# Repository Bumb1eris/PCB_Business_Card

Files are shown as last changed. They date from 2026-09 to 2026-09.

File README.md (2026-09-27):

# Snake PCB Business Card

A business card you can play: a tilt-controlled Snake game on a 7×5 LED matrix, powered by a coin cell.

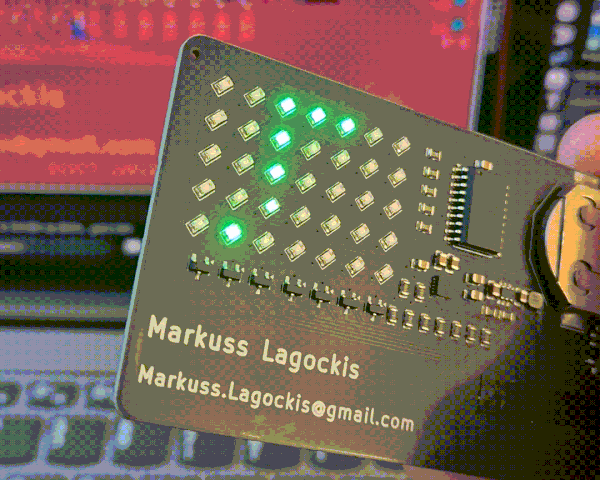
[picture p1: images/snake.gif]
Snake game running on the card


## Why I built it

I designed this card to hand out at TechIndustry, the largest tech expo in the Baltics. A paper card gets thrown away. A card that plays Snake gets passed around.

The original idea was a fluid simulation, but on a 7×5 matrix it just looked like random blinking, so it became Snake instead.

## How to play

- **Flip the switch.** The snake starts moving.
- **Tilt the card** to steer.
- **Crash, and your score appears.** The matrix fills one LED per point. If you fill the whole screen, it rolls over to a second score screen.
- **Shake the card** to start a new game.

## Hardware

| | |
|---|---|
| **MCU** | ATtiny1616 |
| **Accelerometer** | MMA8451 |
| **Power** | CR2032 coin cell → MCP1640 boost converter → stable 3.3 V |
| **Display** | 35 LEDs in a 7×5 multiplexed matrix |
| **PCB** | 2-layer, credit card size, fabricated and assembled by JLCPCB |
| **Cost** | ~€6 per card, assembled |

### How the matrix works

The rows are driven directly from the MCU pins through 22 Ω resistors. The columns are switched by a row of SOT-23 transistors along the bottom of the board. The firmware scans through the columns fast enough that the whole matrix looks lit at once.

The LEDs are rotated 45°. Together with the transistor array underneath, the matrix wiring is some of my cleanest routing work, and it worked on the first try.

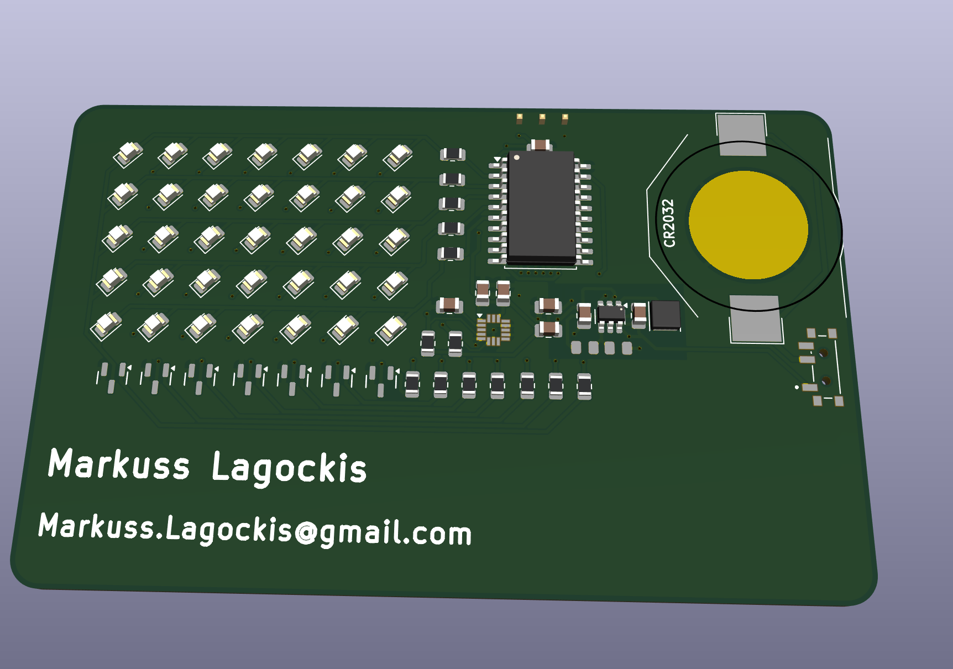
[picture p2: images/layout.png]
PCB layout

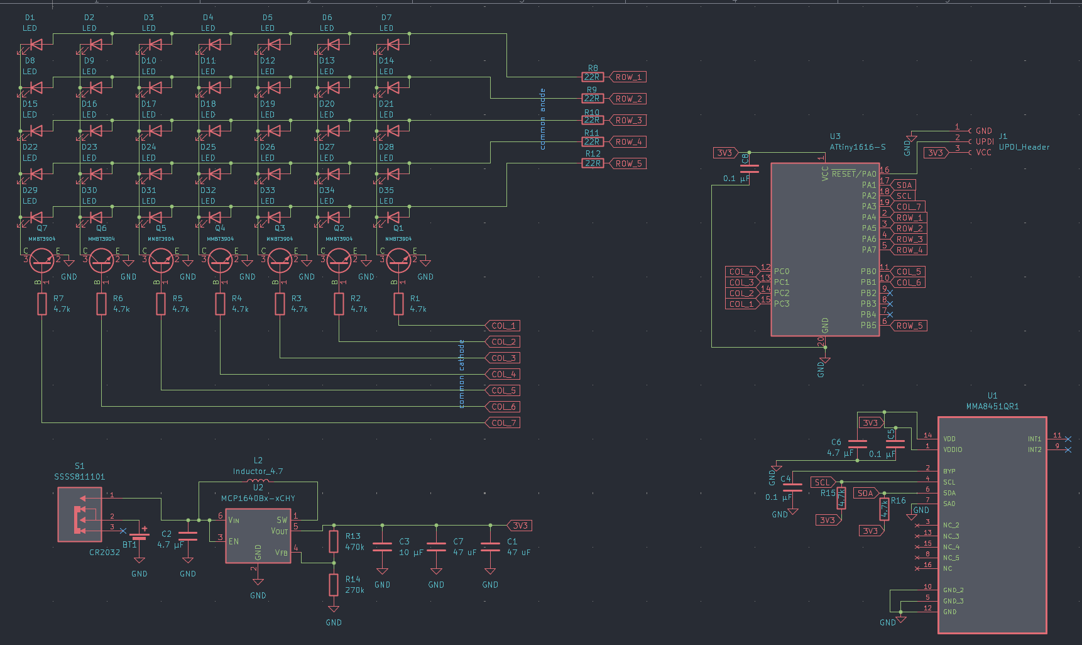
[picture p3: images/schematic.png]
Schematic


## Battery life

- **Switched on:** about 3 days of continuous use
- **Switched off:** about a year or two in storage

## Firmware

Written in the Arduino IDE. The ATtiny1616 is programmed over UPDI, using an Arduino Nano as a makeshift UPDI programmer.

### Flashing

1. Install the [megaTinyCore](https://github.com/SpenceKonde/megaTinyCore) board package in the Arduino IDE.
2. Flash an Arduino Nano with the UPDI programmer sketch (jtag2updi) and wire it to the card's UPDI pin.
3. Select **ATtiny1616** as the board and the Nano as the programmer.
4. Open `firmware/snake/snake.ino` and upload.

## Repository structure

```
firmware/
  snake/          Arduino sketch
hardware/
  kicad/          KiCad project files
  schematic.pdf
  gerbers/        ready to send to a fab
  bom.csv
images/
```

## Status

✅ **v1 finished.** Cards were built, handed out, and work as designed.

🚧 **v2 planned.** The main change: swap the MMA8451 for a proper IMU. The accelerometer isn't responsive enough, so steering can feel sluggish.

## License

Hardware/Firmware: MIT

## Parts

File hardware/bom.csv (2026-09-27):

Designator | Footprint | Quantity | Value | LCSC Part #
BT1 | CR2032 | 1 | CR2032
C1, C7 | 0805 | 2 | 47 uF
C2, C6 | 0805 | 2 | 4.7 µF
C3 | 0805 | 1 | 10 µF
C4, C5, C8 | 0805 | 3 | 0.1 µF
D1, D10, D11, D12, D13, D14, D15, D16, D17, D18, D19, D2, D20, D21, D22, D23, D24, D25, D26, D27, D28, D29, D3, D30, D31, D32, D33, D34, D35, D4, D5, D6, D7, D8, D9 | 0805 | 35 | LED | C2297
J1 | UPDI_P=2.54mm | 1 | UPDI_Header
L2 | L_APV_ANR3010 | 1 | Inductor_4.7 | C135233
Q1, Q2, Q3, Q4, Q5, Q6, Q7 | Q_SOT-23 | 7 | MMBT3904 | C7420353
R1, R15, R16, R2, R3, R4, R5, R6, R7 | 0805 | 9 | 4.7k
R10, R11, R12, R8, R9 | 0805 | 5 | 22R
R13 | R_0805 | 1 | 470k
R14 | R_0805 | 1 | 270k
S1 | SW_SSSS811101Real | 1 | SSSS811101
U1 | QFN50P300X300X100-16N | 1 | MMA8451QR1 | C118083
U2 | SOT-23-6 | 1 | MCP1640Bx-xCHY
U3 | SOIC-20W_7.5x12.8mm_P1.27mm | 1 | ATtiny1616-S

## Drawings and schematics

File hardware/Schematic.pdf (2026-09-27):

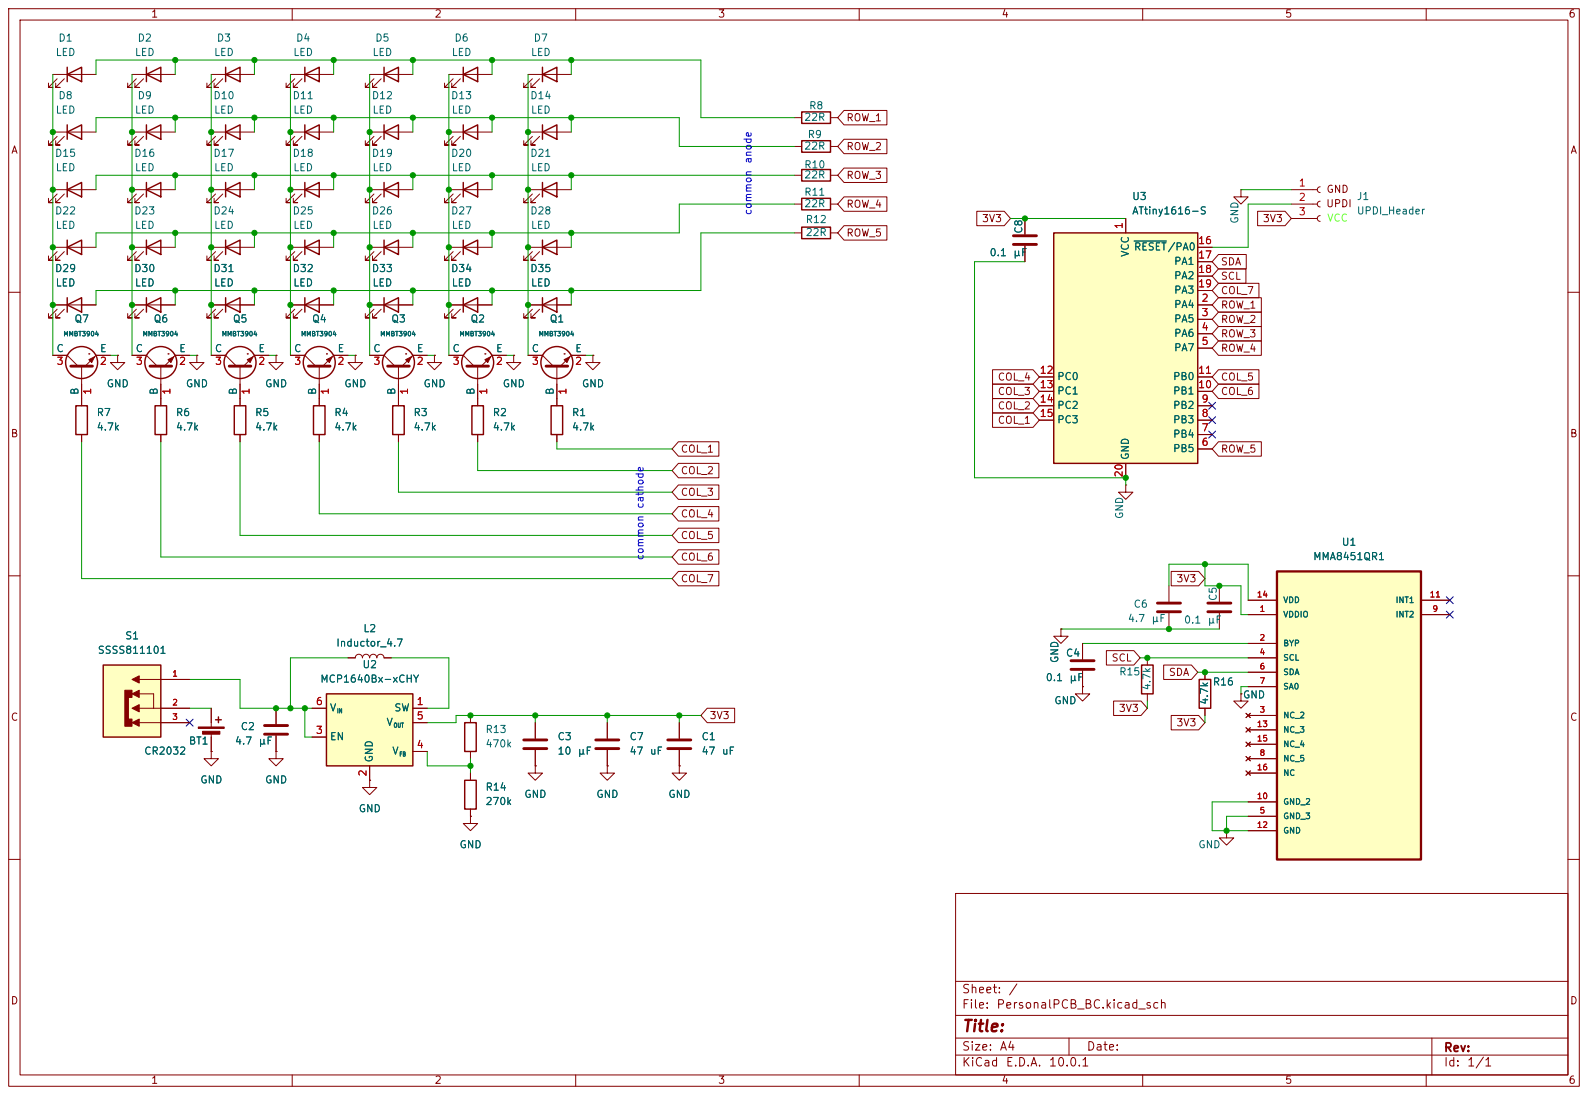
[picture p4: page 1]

D15 LED | D16 LED | LED | D18 LED | MMBT3904 D12 D19 LED | D20 LED

D22 LED | D23 LED | D24 LED | LED | LED | D27 LED

D29 D29 LED LED | D30 LED | D31 LED LED | D32 D32 LED | D33 D33 LED LED | D34 LED LED | D35 D35 LED

Size: A4 | Rev:
KiCad E.D.A. 10.0.1 | Id: 1/1

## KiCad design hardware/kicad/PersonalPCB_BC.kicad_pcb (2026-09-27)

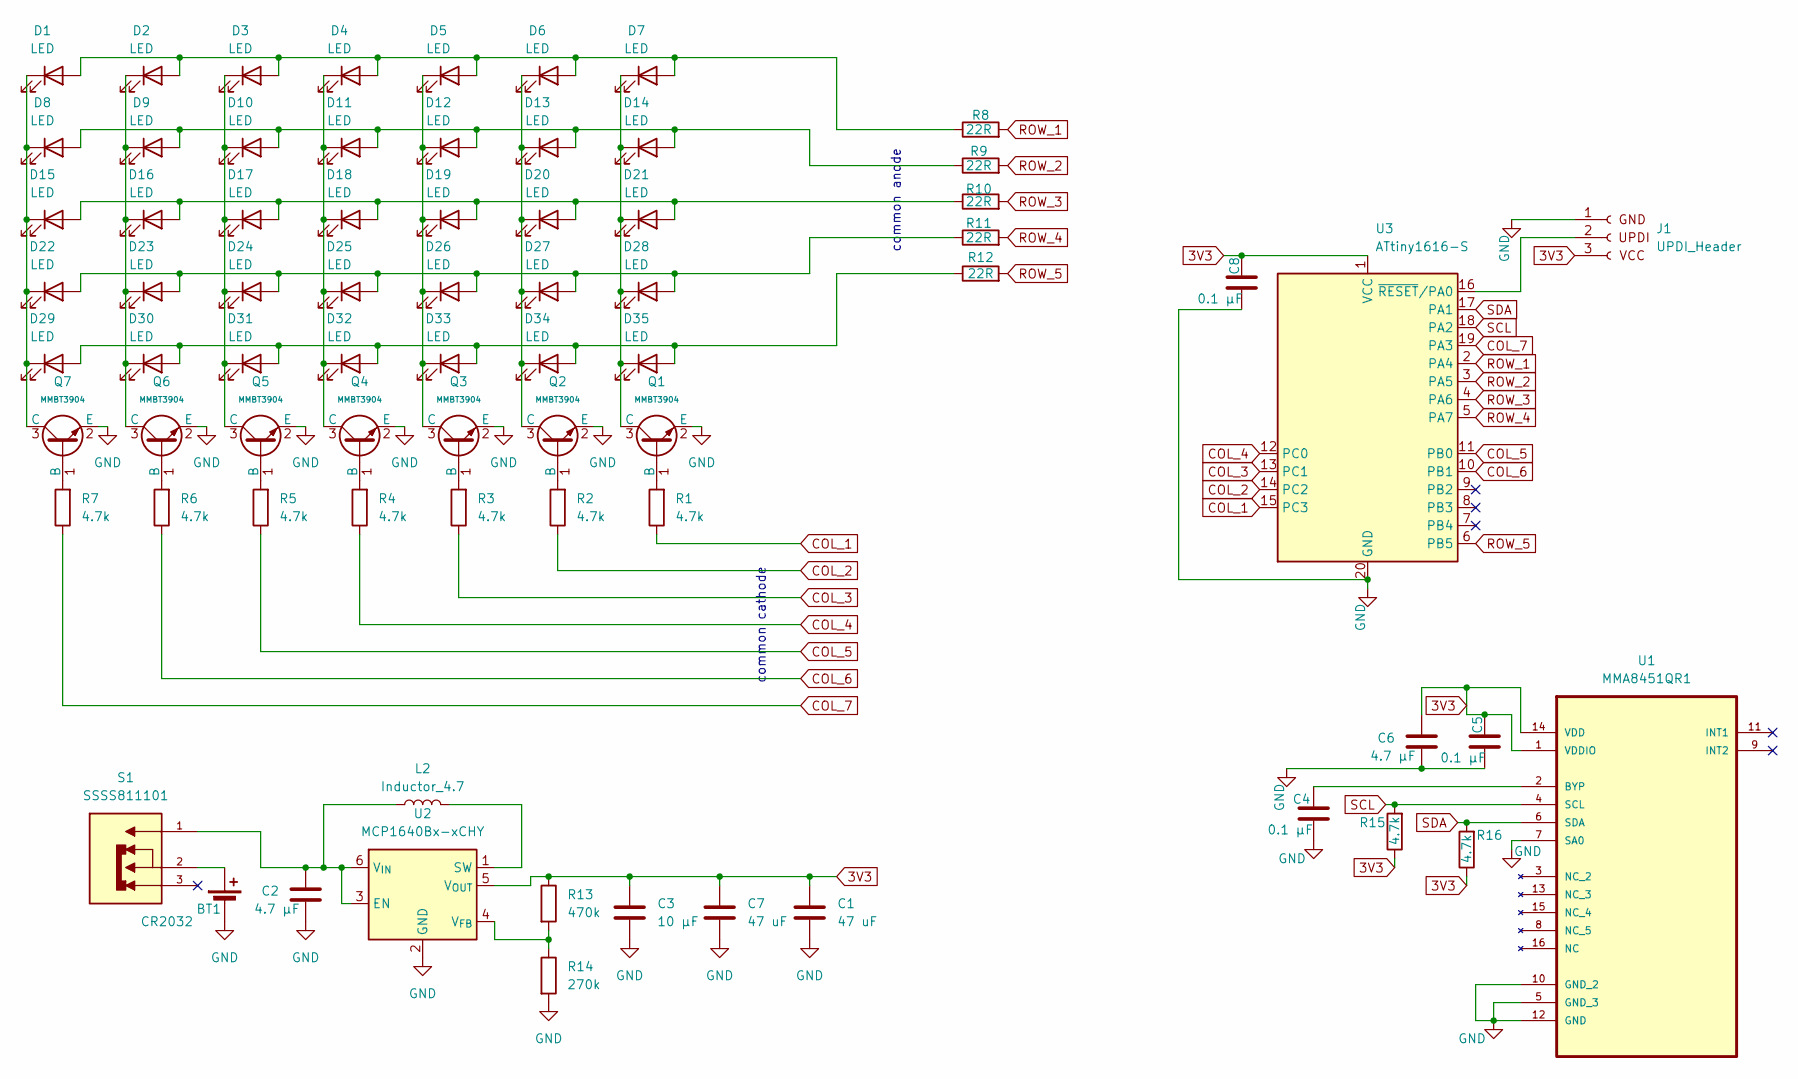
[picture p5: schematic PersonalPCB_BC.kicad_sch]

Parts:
BT1: CR2032
C1, C7: 47 uF; C_0805_2012Metric; JLCPCB Part # C16780
C2, C6: 4.7 µF; C_0805_2012Metric
C3: 10 µF; C_0805_2012Metric
C4, C5, C8: 0.1 µF; C_0805_2012Metric
D1, D2, D3, D4, D5, D6, D7, D8, D9, D10, D11, D12, D13, D14, D15, D16, D17, D18, D19, D20, D21, D22, D23, D24, D25, D26, D27, D28, D29, D30, D31, D32, D33, D34, D35: LED; LED_0805_2012Metric; JLCPCB Part # C2297
J1: UPDI_Header; UPDI_P=2.54mm
L2: Inductor_4.7; L_APV_ANR3010; JLCPCB Part # C135233
Q1, Q2, Q3, Q4, Q5, Q6, Q7: MMBT3904; Q_SOT-23; Part MMBT3904; LCSC C7420353
R1, R2, R3, R4, R5, R6, R7, R15, R16: 4.7k; R_0805_2012Metric
R8, R9, R10, R11, R12: 22R; R_0805_2012Metric
R13: 470k; R_0805
R14: 270k; R_0805
S1: SSSS811101; SW_SSSS811101Real; PARTREV N/A
U1: MMA8451QR1; QFN50P300X300X100-16N; JLCPCB Part # C118083
U2: MCP1640Bx-xCHY; SOT-23-6
U3: ATtiny1616-S; SOIC-20W_7.5x12.8mm_P1.27mm

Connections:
3V3: C1.1, C3.1, C5.1, C6.1, C7.1, C8.1, J1.3 (VCC), R13.1, R15.1, R16.1, U1.1 (VDDIO), U1.14 (VDD), U2.5 (V_{OUT}), U3.1 (VCC)
COL_1: R1.1, U3.15 (PC3)
COL_2: R2.1, U3.14 (PC2)
COL_3: R3.1, U3.13 (PC1)
COL_4: R4.1, U3.12 (PC0)
COL_5: R5.1, U3.11 (PB0)
COL_6: R6.1, U3.10 (PB1)
COL_7: R7.1, U3.19 (PA3)
GND: BT1.2 (-), C1.2, C2.2, C3.2, C4.2, C5.2, C6.2, C7.2, C8.2, J1.1 (GND), Q1.2 (E), Q2.2 (E), Q3.2 (E), Q4.2 (E), Q5.2 (E), Q6.2 (E), Q7.2 (E), R14.2, U1.5 (GND_3), U1.7 (SA0), U1.10 (GND_2), U1.12 (GND), U2.2 (GND), U3.20 (GND)
unnamed: BT1.1 (+), S1.2
unnamed: D1.2 (A), D2.2 (A), D3.2 (A), D4.2 (A), D5.2 (A), D6.2 (A), D7.2 (A), R8.1
unnamed: D1.1 (K), D8.1 (K), D15.1 (K), D22.1 (K), D29.1 (K), Q7.3 (C)
unnamed: D8.2 (A), D9.2 (A), D10.2 (A), D11.2 (A), D12.2 (A), D13.2 (A), D14.2 (A), R9.1
unnamed: D3.1 (K), D10.1 (K), D17.1 (K), D24.1 (K), D31.1 (K), Q5.3 (C)
unnamed: D4.1 (K), D11.1 (K), D18.1 (K), D25.1 (K), D32.1 (K), Q4.3 (C)
unnamed: D5.1 (K), D12.1 (K), D19.1 (K), D26.1 (K), D33.1 (K), Q3.3 (C)
unnamed: D6.1 (K), D13.1 (K), D20.1 (K), D27.1 (K), D34.1 (K), Q2.3 (C)
unnamed: D7.1 (K), D14.1 (K), D21.1 (K), D28.1 (K), D35.1 (K), Q1.3 (C)
unnamed: D15.2 (A), D16.2 (A), D17.2 (A), D18.2 (A), D19.2 (A), D20.2 (A), D21.2 (A), R10.1
unnamed: D2.1 (K), D9.1 (K), D16.1 (K), D23.1 (K), D30.1 (K), Q6.3 (C)
unnamed: D22.2 (A), D23.2 (A), D24.2 (A), D25.2 (A), D26.2 (A), D27.2 (A), D28.2 (A), R11.1
unnamed: D29.2 (A), D30.2 (A), D31.2 (A), D32.2 (A), D33.2 (A), D34.2 (A), D35.2 (A), R12.1
unnamed: J1.2 (UPDI), U3.16 (~RESET/PA0)
unnamed: Q1.1 (B), R1.2
unnamed: Q2.1 (B), R2.2
unnamed: Q3.1 (B), R3.2
unnamed: Q4.1 (B), R4.2
unnamed: Q5.1 (B), R5.2
unnamed: Q6.1 (B), R6.2
unnamed: Q7.1 (B), R7.2
unnamed: C4.1, U1.2 (BYP)
unnamed: C2.1, L2.1, S1.1, U2.3 (EN), U2.6 (V_{IN})
unnamed: L2.2, U2.1 (SW)
unnamed: R13.2, R14.1, U2.4 (V_{FB})
ROW_1: R8.2, U3.2 (PA4)
ROW_2: R9.2, U3.3 (PA5)
ROW_3: R10.2, U3.4 (PA6)
ROW_4: R11.2, U3.5 (PA7)
ROW_5: R12.2, U3.6 (PB5)
SCL: R15.2, U1.4 (SCL), U3.18 (PA2)
SDA: R16.2, U1.6 (SDA), U3.17 (PA1)

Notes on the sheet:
common cathode
common anode

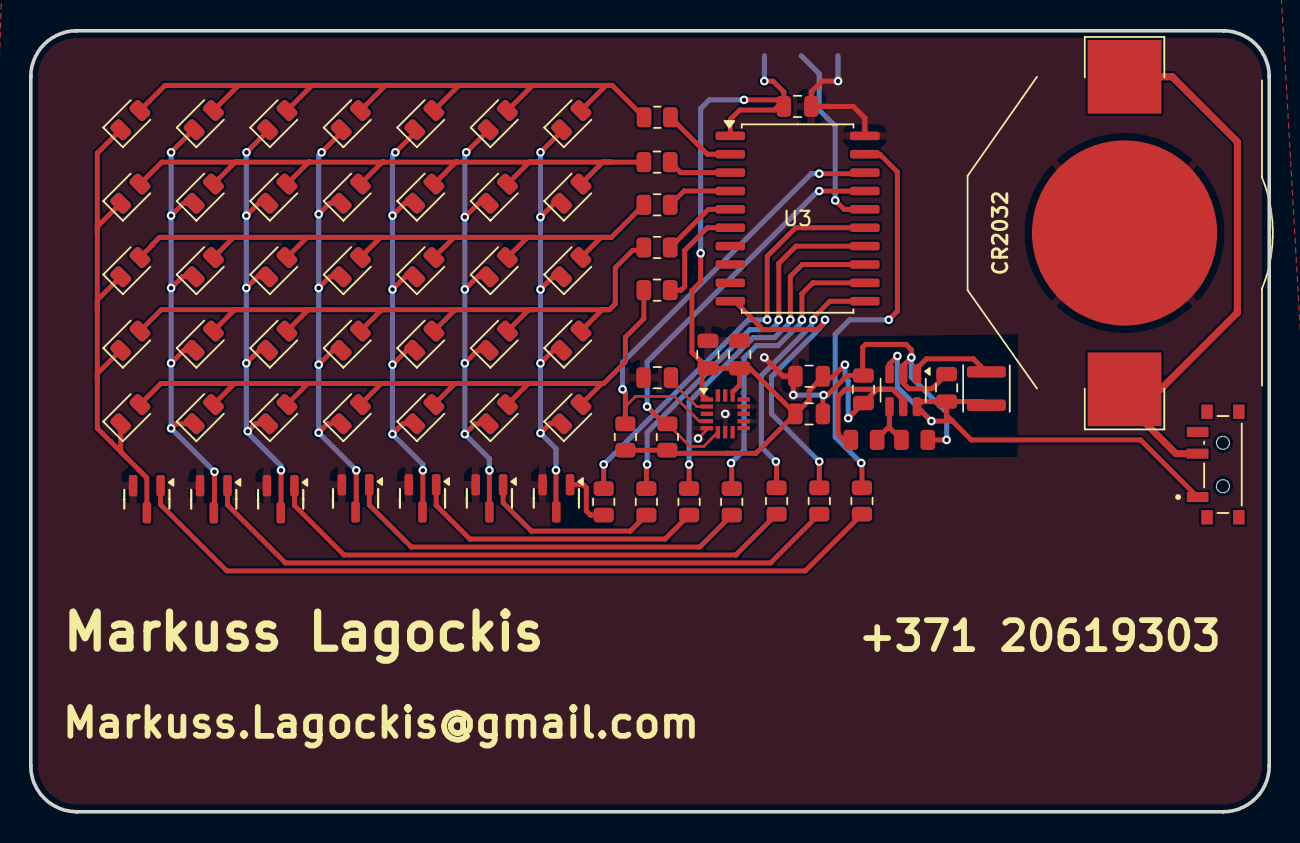
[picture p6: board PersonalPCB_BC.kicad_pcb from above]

Board: 2 copper layers, 85.6 x 54.0 mm, 73 parts (1 on the bottom side), 41 nets.

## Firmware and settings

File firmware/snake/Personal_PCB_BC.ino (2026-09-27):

#include <SoftwareWire.h>

// --- CONFIGURATION ---
const int SLEEP_TIMEOUT_MINUTES = 1;  // Minutes of inactivity before turning off LEDs

// --- Pin Definitions ---
const int rowPins[] = {0, 1, 2, 3, 4};
const int colPins[] = {16, 8, 9, 10, 11, 12, 13};

// --- I2C Configuration ---
const int I2C_SDA_PIN = 14; 
const int I2C_SCL_PIN = 15; 
const int MMA_ADDR = 0x1C;
SoftwareWire i2c(I2C_SDA_PIN, I2C_SCL_PIN);

// --- MMA8451 Registers ---
const int REG_CTRL_REG1 = 0x2A;
const int REG_OUT_X_MSB = 0x01;

// --- Display Buffer ---
bool display[5][7];
int brightness[5][7];

// --- Snake Game Variables ---
struct SnakeSegment {
  int x, y;
};

SnakeSegment snake[35];
int snakeLength = 1;
int headX = 3, headY = 2;

// Food position
int foodX = 5, foodY = 1;
unsigned long foodSpawnTime = 0;

// Game state
bool gameOver = false;
int score = 0;

// Movement
int dirX = 1, dirY = 0;
unsigned long lastMoveTime = 0;
const int MOVE_INTERVAL = 500;

// --- Sensor Data ---
float tiltX = 0;
float tiltY = 0;
float baseX = 0;
float baseY = 0;

// Smoothed sensor values
float smoothTiltX = 0;
float smoothTiltY = 0;
const float SENSOR_SMOOTHING = 0.3;

// Shake detection
float lastTiltX = 0;
float lastTiltY = 0;
int shakeCount = 0;
unsigned long lastShakeTime = 0;

// Sleep mode
unsigned long lastActivityTime = 0;
const unsigned long SLEEP_TIMEOUT = SLEEP_TIMEOUT_MINUTES * 60000UL;
bool ledsOff = false;

// --- Game over animation ---
unsigned long gameOverStartTime = 0;
int scoreDisplayCount = 0;
unsigned long lastScoreLightTime = 0;
const int SCORE_LIGHT_DELAY = 400;

// --- Timing ---
unsigned long lastUpdate = 0;
const int UPDATE_INTERVAL = 30;

void setup() {
  // Initialize pins
  for (int i = 0; i < 5; i++) {
    pinMode(rowPins[i], OUTPUT);
    digitalWrite(rowPins[i], LOW);
  }
  for (int i = 0; i < 7; i++) {
    pinMode(colPins[i], OUTPUT);
    digitalWrite(colPins[i], LOW);
  }
  pinMode(5, OUTPUT); digitalWrite(5, LOW);
  pinMode(6, OUTPUT); digitalWrite(6, LOW);
  pinMode(7, OUTPUT); digitalWrite(7, LOW);

  // Initialize I2C
  i2c.begin();
  delay(100);

  // Check accelerometer
  i2c.beginTransmission(MMA_ADDR);
  if (i2c.endTransmission() != 0) {
    while(1) {
      digitalWrite(rowPins[0], HIGH);
      digitalWrite(colPins[0], HIGH);
      delay(200);
      digitalWrite(colPins[0], LOW);
      digitalWrite(rowPins[0], LOW);
      delay(200);
    }
  }

  // Configure accelerometer
  i2c.beginTransmission(MMA_ADDR);
  i2c.write(REG_CTRL_REG1);
  i2c.write(0x00);
  i2c.endTransmission();
  delay(10);

  i2c.beginTransmission(MMA_ADDR);
  i2c.write(REG_CTRL_REG1);
  i2c.write(0x01);
  i2c.endTransmission();
  delay(10);

  // Calibrate
  float sumX = 0, sumY = 0;
  for (int i = 0; i < 20; i++) {
    float x, y;
    readAccel(x, y);
    sumX += x;
    sumY += y;
    delay(10);
  }
  baseX = sumX / 20.0;
  baseY = sumY / 20.0;

  // Initialize snake
  snake[0].x = 3;
  snake[0].y = 2;
  snakeLength = 1;

  // Place first food
  placeFood();
  
  lastActivityTime = millis();

  clearDisplay();
}

void loop() {
  unsigned long now = millis();
  
  // Check for timeout - turn off LEDs
  if (!ledsOff && (now - lastActivityTime > SLEEP_TIMEOUT)) {
    ledsOff = true;
    clearDisplay();
  }
  
  // If LEDs are off, check for wake (shake)
  if (ledsOff) {
    if (now - lastUpdate >= UPDATE_INTERVAL) {
      lastUpdate = now;
      
      float rawX, rawY;
      readAccel(rawX, rawY);
      tiltX = rawX - baseX;
      tiltY = rawY - baseY;
      
      // Use same shake detection as game reset
      float deltaX = abs(tiltX - lastTiltX);
      float deltaY = abs(tiltY - lastTiltY);
      
      if (deltaX > 3500 || deltaY > 3500) {
        shakeCount++;
        lastShakeTime = now;
      }
      
      if (now - lastShakeTime > 400) {
        shakeCount = 0;
      }
      
      // If shaken hard (5+ rapid movements), wake up and restart game
      if (shakeCount >= 5) {
        ledsOff = false;
        lastActivityTime = now;
        
        // Reset game
        snakeLength = 1;
        snake[0].x = 3;
        snake[0].y = 2;
        dirX = 1;
        dirY = 0;
        score = 0;
        gameOver = false;
        scoreDisplayCount = 0;
        shakeCount = 0;
        placeFood();
      }
      
      lastTiltX = tiltX;
      lastTiltY = tiltY;
    }
    return;
  }
  
  // Multiplex display
  for (int r = 0; r < 5; r++) {
    digitalWrite(rowPins[r], HIGH);
    for (int c = 0; c < 7; c++) {
      if (display[r][c]) {
        digitalWrite(colPins[c], HIGH);
        if (brightness[r][c] == 3) {
          delayMicroseconds(5);
        } else if (brightness[r][c] == 2) {
          delayMicroseconds(2);
        } else if (brightness[r][c] == 1) {
          delayMicroseconds(1);
        }
        digitalWrite(colPins[c], LOW);
      }
    }
    digitalWrite(rowPins[r], LOW);
    delayMicroseconds(10);
  }
  
  if (gameOver) {
    // Calculate target LED count based on score
    int targetLeds;
    if (score <= 23) {
      targetLeds = (score * 3 + 1) / 2;
    } else {
      targetLeds = score - 23;
    }
    
    // Animate score counting up
    if (now - lastScoreLightTime > SCORE_LIGHT_DELAY) {
      lastScoreLightTime = now;
      if (scoreDisplayCount < targetLeds) {
        scoreDisplayCount++;
        lastActivityTime = now;
      }
    }
    
    renderScrollingScore();
    
    // Check for shake to reset
    if (now - lastUpdate >= UPDATE_INTERVAL) {
      lastUpdate = now;
      float rawX, rawY;
      readAccel(rawX, rawY);
      tiltX = rawX - baseX;
      tiltY = rawY - baseY;
      
      float deltaX = abs(tiltX - lastTiltX);
      float deltaY = abs(tiltY - lastTiltY);
      
      if (deltaX > 3500 || deltaY > 3500) {
        shakeCount++;
        lastShakeTime = now;
        lastActivityTime = now;
      }
      
      if (now - lastShakeTime > 400) {
        shakeCount = 0;
      }
      
      if (shakeCount >= 5) {
        snakeLength = 1;
        snake[0].x = 3;
        snake[0].y = 2;
        dirX = 1;
        dirY = 0;
        score = 0;
        gameOver = false;
        shakeCount = 0;
        scoreDisplayCount = 0;
        lastActivityTime = now;
        placeFood();
      }
      
      lastTiltX = tiltX;
      lastTiltY = tiltY;
    }
    return;
  }

  // Update sensor reading
  if (now - lastUpdate >= UPDATE_INTERVAL) {
    lastUpdate = now;

    float rawX, rawY;
    readAccel(rawX, rawY);
    tiltX = rawX - baseX;
    tiltY = rawY - baseY;
    
    if (abs(tiltX) > 300 || abs(tiltY) > 300) {
      lastActivityTime = now;
    }
    
    smoothTiltX = smoothTiltX * (1.0 - SENSOR_SMOOTHING) + tiltX * SENSOR_SMOOTHING;
    smoothTiltY = smoothTiltY * (1.0 - SENSOR_SMOOTHING) + tiltY * SENSOR_SMOOTHING;

    updateDirection();
    
    lastTiltX = tiltX;
    lastTiltY = tiltY;
  }

  // Move snake
  if (now - lastMoveTime >= MOVE_INTERVAL) {
    lastMoveTime = now;
    lastActivityTime = now;
    moveSnake();
  }

  renderGame();
}

void readAccel(float &x, float &y) {
  i2c.beginTransmission(MMA_ADDR);
  i2c.write(REG_OUT_X_MSB);
  i2c.endTransmission(false);
  i2c.requestFrom(MMA_ADDR, 4);
  
  int16_t rawX = (i2c.read() << 8) | i2c.read();
  int16_t rawY = (i2c.read() << 8) | i2c.read();
  
  x = (float)(rawX >> 2);
  y = (float)(rawY >> 2);
}

void updateDirection() {
  float absX = abs(smoothTiltX);
  float absY = abs(smoothTiltY);
  
  const float THRESHOLD = 500.0;
  
  if (absX > THRESHOLD || absY > THRESHOLD) {
    int newDirX = 0;
    int newDirY = 0;
    
    if (absX > absY) {
      newDirX = (smoothTiltX > 0) ? 1 : -1;
      newDirY = 0;
    } else {
      newDirX = 0;
      newDirY = (smoothTiltY > 0) ? -1 : 1;
    }
    
    if (snakeLength >= 2) {
      int nextX = snake[0].x + newDirX;
      int nextY = snake[0].y + newDirY;
      
      if (nextX < 0) nextX = 6;
      if (nextX > 6) nextX = 0;
      if (nextY < 0) nextY = 4;
      if (nextY > 4) nextY = 0;
      
      if (nextX == snake[1].x && nextY == snake[1].y) {
        return;
      }
    }
    
    dirX = newDirX;
    dirY = newDirY;
  }
}

void moveSnake() {
  int newHeadX = snake[0].x + dirX;
  int newHeadY = snake[0].y + dirY;
  
  if (newHeadX < 0) newHeadX = 6;
  if (newHeadX > 6) newHeadX = 0;
  if (newHeadY < 0) newHeadY = 4;
  if (newHeadY > 4) newHeadY = 0;
  
  for (int i = 0; i < snakeLength; i++) {
    if (snake[i].x == newHeadX && snake[i].y == newHeadY) {
      gameOver = true;
      gameOverStartTime = millis();
      return;
    }
  }
  
  bool ateFood = false;
  if (newHeadX == foodX && newHeadY == foodY) {
    ateFood = true;
    score++;
    placeFood();
  }
  
  if (!ateFood) {
    for (int i = snakeLength - 1; i > 0; i--) {
      snake[i] = snake[i - 1];
    }
  } else {
    for (int i = snakeLength; i > 0; i--) {
      snake[i] = snake[i - 1];
    }
    snakeLength++;
  }
  
  snake[0].x = newHeadX;
  snake[0].y = newHeadY;
}

void placeFood() {
  bool validPosition = false;
  
  while (!validPosition) {
    foodX = random(0, 7);
    foodY = random(0, 5);
    
    validPosition = true;
    for (int i = 0; i < snakeLength; i++) {
      if (snake[i].x == foodX && snake[i].y == foodY) {
        validPosition = false;
        break;
      }
    }
  }
  
  foodSpawnTime = millis();
}

void renderGame() {
  clearDisplay();
  
  for (int i = 0; i < snakeLength; i++) {
    display[snake[i].y][snake[i].x] = true;
    brightness[snake[i].y][snake[i].x] = 1;
  }
  
  unsigned long timeSinceSpawn = millis() - foodSpawnTime;
  bool showFood = true;
  
  if (timeSinceSpawn < 400) {
    int cycle = timeSinceSpawn % 100;
    showFood = (cycle >= 50);
  }
  
  if (showFood) {
    display[foodY][foodX] = true;
    brightness[foodY][foodX] = 3;
  }
}

void renderScrollingScore() {
  clearDisplay();
  
  int totalLeds;
  
  if (score <= 23) {
    totalLeds = (score * 3 + 1) / 2;
  } else {
    totalLeds = score - 23;
  }
  
  int ledsToShow = min(scoreDisplayCount, totalLeds);
  
  if (score <= 23) {
    for (int i = 0; i < ledsToShow && i < 35; i++) {
      int row = i / 7;
      int col = i % 7;
      
      display[row][col] = true;
      brightness[row][col] = 2;
    }
  } else {
    for (int i = 0; i < ledsToShow && i < 35; i++) {
      int col = i / 5;
      int row = 4 - (i % 5);
      
      display[row][col] = true;
      brightness[row][col] = 2;
    }
  }
}

void clearDisplay() {
  for (int r = 0; r < 5; r++) {
    for (int c = 0; c < 7; c++) {
      display[r][c] = false;
      brightness[r][c] = 0;
    }
  }
}
